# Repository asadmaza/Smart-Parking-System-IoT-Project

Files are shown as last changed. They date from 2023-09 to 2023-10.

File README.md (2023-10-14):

# Group3-CITS5506-2023
Repository for Group 3 Course CITS5506 2023 Second Semester

# Final Code to Use in Presentation and Vide
1. webApplication/indexAlternate.py
2. 8. RPI Local Script/integration_scriptV3.py

## To Do List
### raspberry Script
    - make a v4 of asad's local script that actually 
        1. publish to the aws iot core topic
        2. subscribe to the aws iot core topic
        3. init the bay states by publish a message to the topic and waiting for the appropriate response

### web application    
    - going to assume the booking entry time is always from right now until designated booking exit time
    - going to assume the reserved bay is only for people who make reservation beforehand
    - if a reservation is expired, then the bay will return to the state of can be reserved and customer needs to reserved it first before park their car in it

    -- Nice to Have --
    - Create input validation for the booking form
    - Change the web UI to accommodate for camera streaming on the situation of the parking bay
    - Send email to customer whenever a parking bay is reserved from the webapp
    - Apply best practice such as separate config

### Potential Improvement
#### Web application side
    - safeguard from racing condition
    - implement payment method
    - user account implementation

## How to run
1. create a new virtual environment
    python3 -m venv venv
2. activate environment
    > on macOS/Linux
        venv/bin/activate
    > on windows
        venv\Scripts\activate.bat
3. install requirement
    pip install -r requirements.txt
4. run the web app
    cd webApplication
    flask --app index run

## How to create local db for testing or maybe funsies
1. install sqlite3
2. cd to webApplicatoin/databaseStruct
3. run
    sqlite3 mockIoTDB.db < initdb.sql 
4. run to populate the mock data to the database
    cat insertToDetail.sql | sqlite3 mockIoTDB.db

## How to contribute
If you are interested to do one of the function that's in the web application section please do this first
1. make a new branch from this aji_branch or main branch if this is already merged
    git checkout -b "<insert branch name>" - format the branch name like yourName_what_you_are_trying_to_do
2. make your changes
3. test it
4. stage and commit your work
    git add . -> do this in the Group3...... folder
    git commit -m "<insert commit message>"
5. push to your branch
    git push origin <branch_name>
6. create a pull request

# Feel free to DM if you have anything to ask

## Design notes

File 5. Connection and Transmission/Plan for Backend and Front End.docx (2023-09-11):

Communication to a Database Proposed architecture for minimum functionality (Work in Progress):

1. AWS IoT Core
  1. Setup
    i. Prepare device

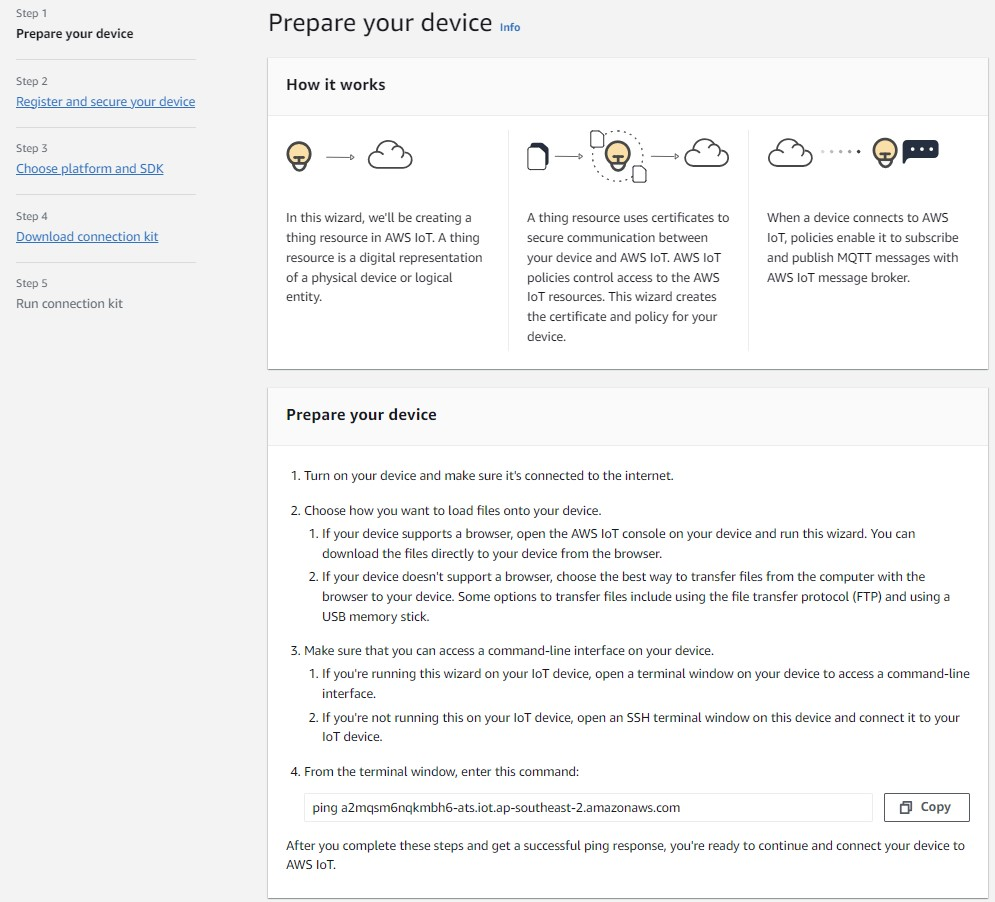
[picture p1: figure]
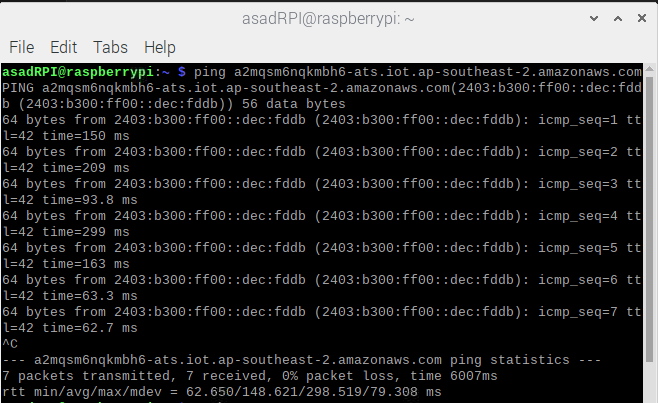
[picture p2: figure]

    ii. Register and secure device

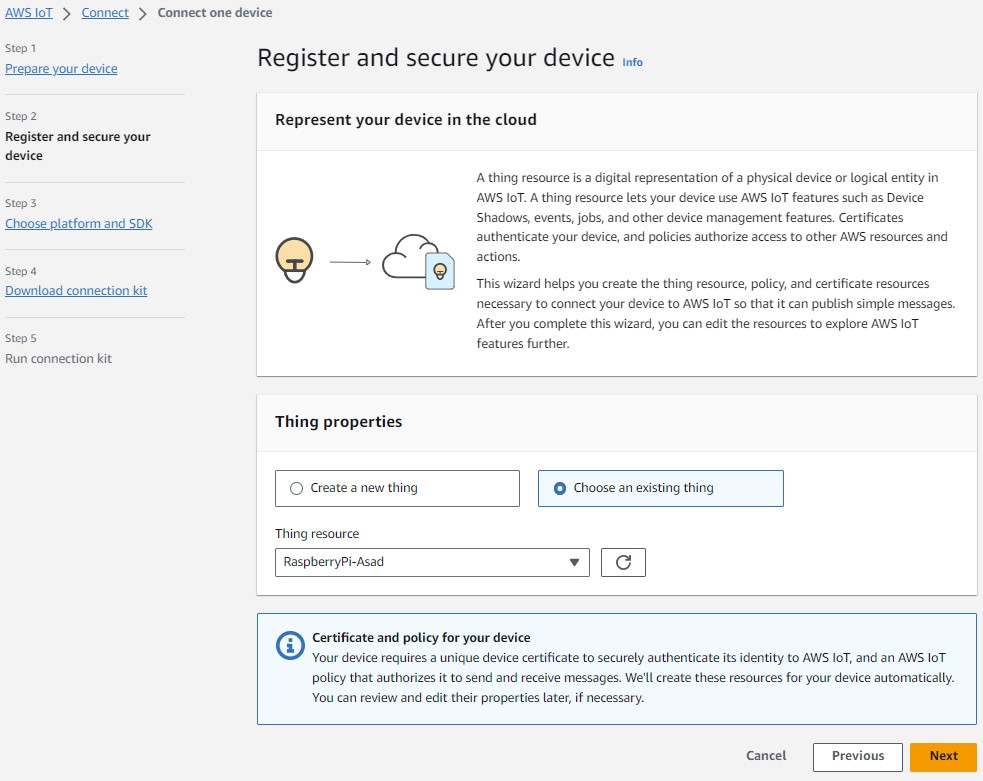
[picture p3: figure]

    iii. Choose platform and SDK

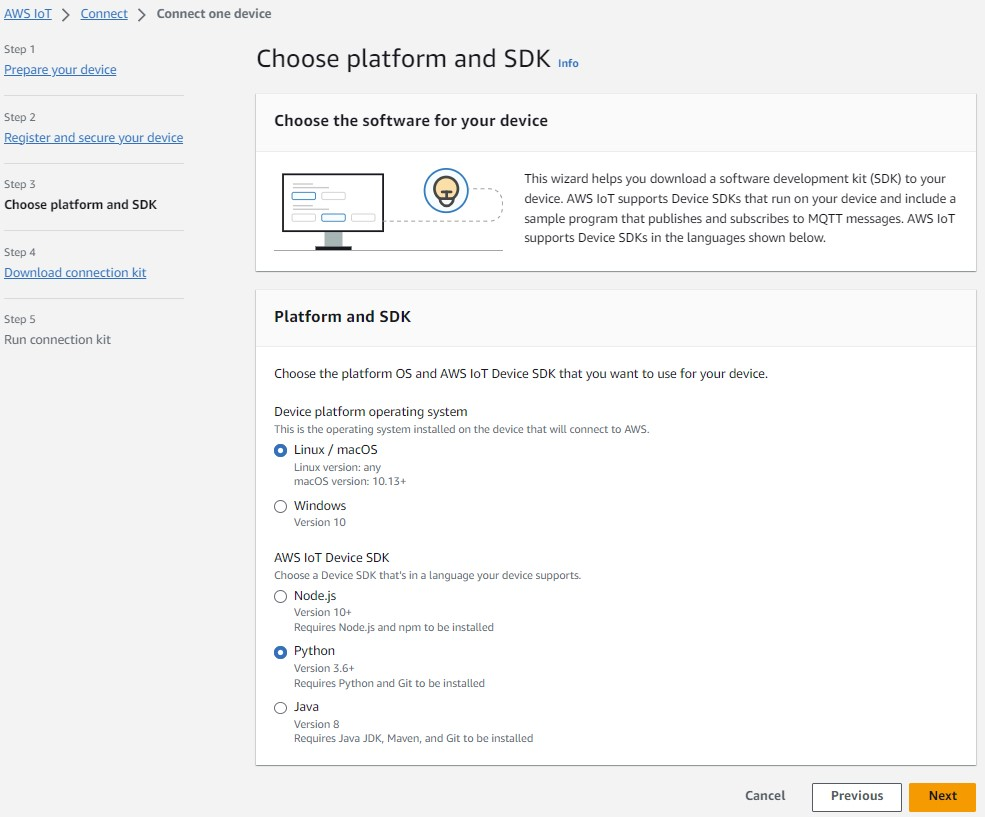
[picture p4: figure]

    iv. Download connection kit

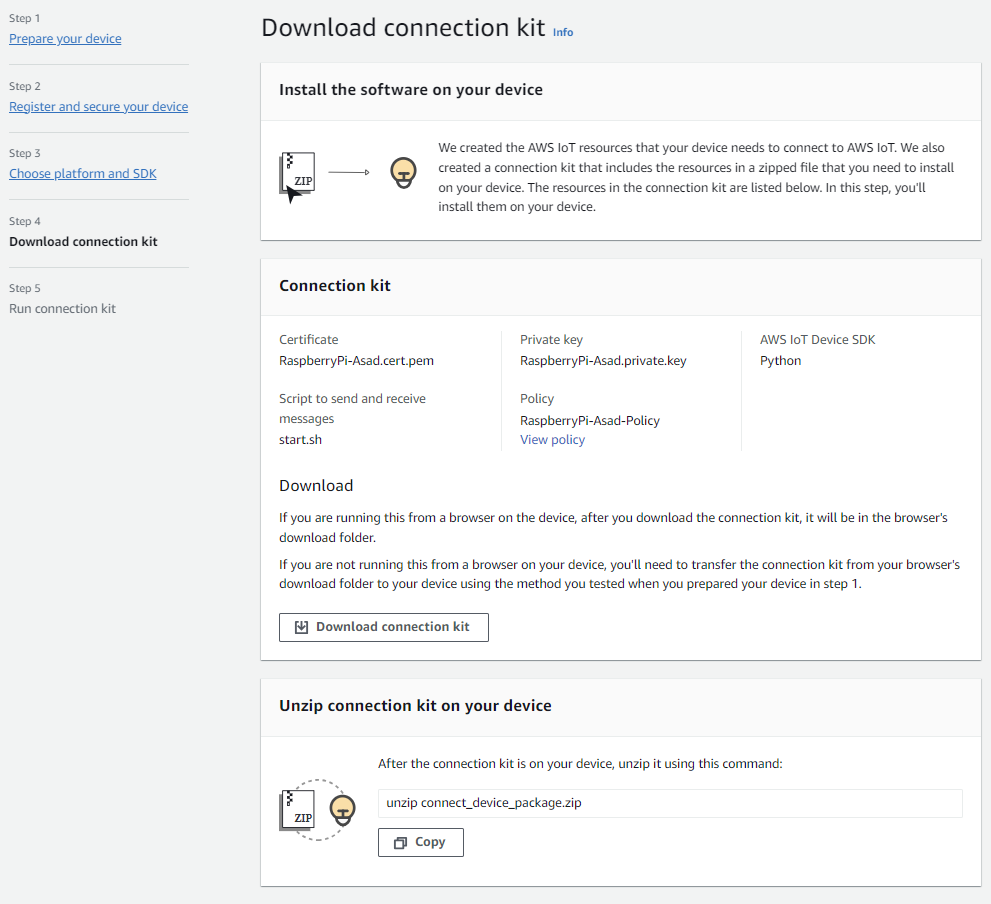
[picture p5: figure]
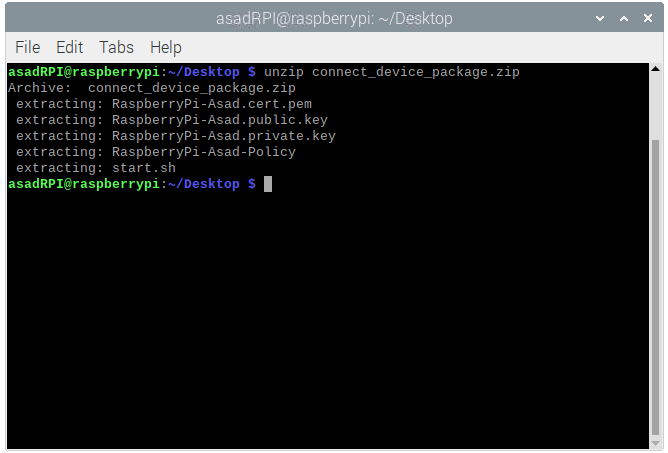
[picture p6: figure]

    v. Run connection kit on device

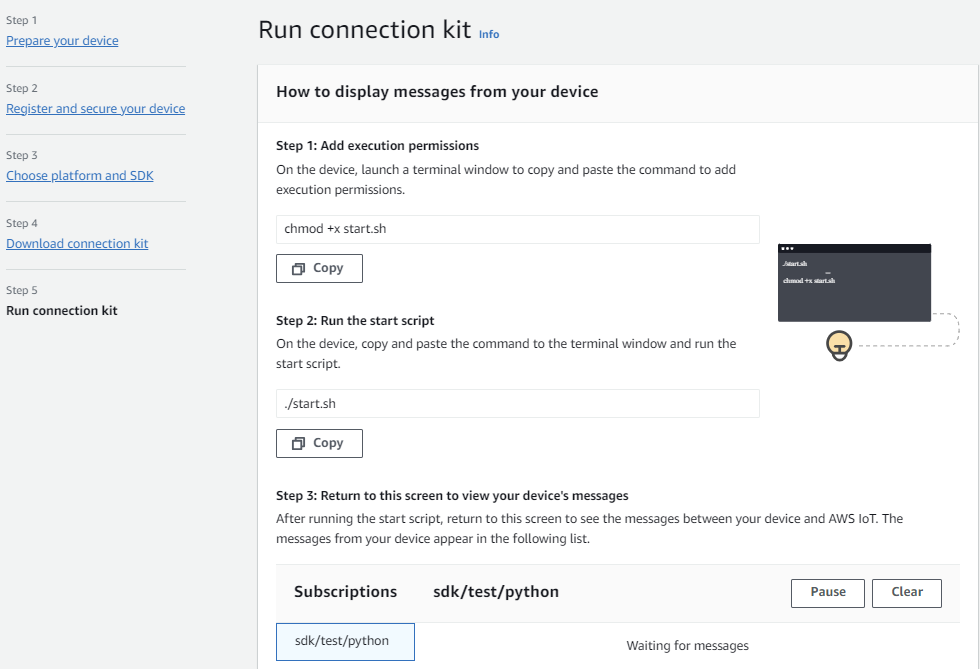
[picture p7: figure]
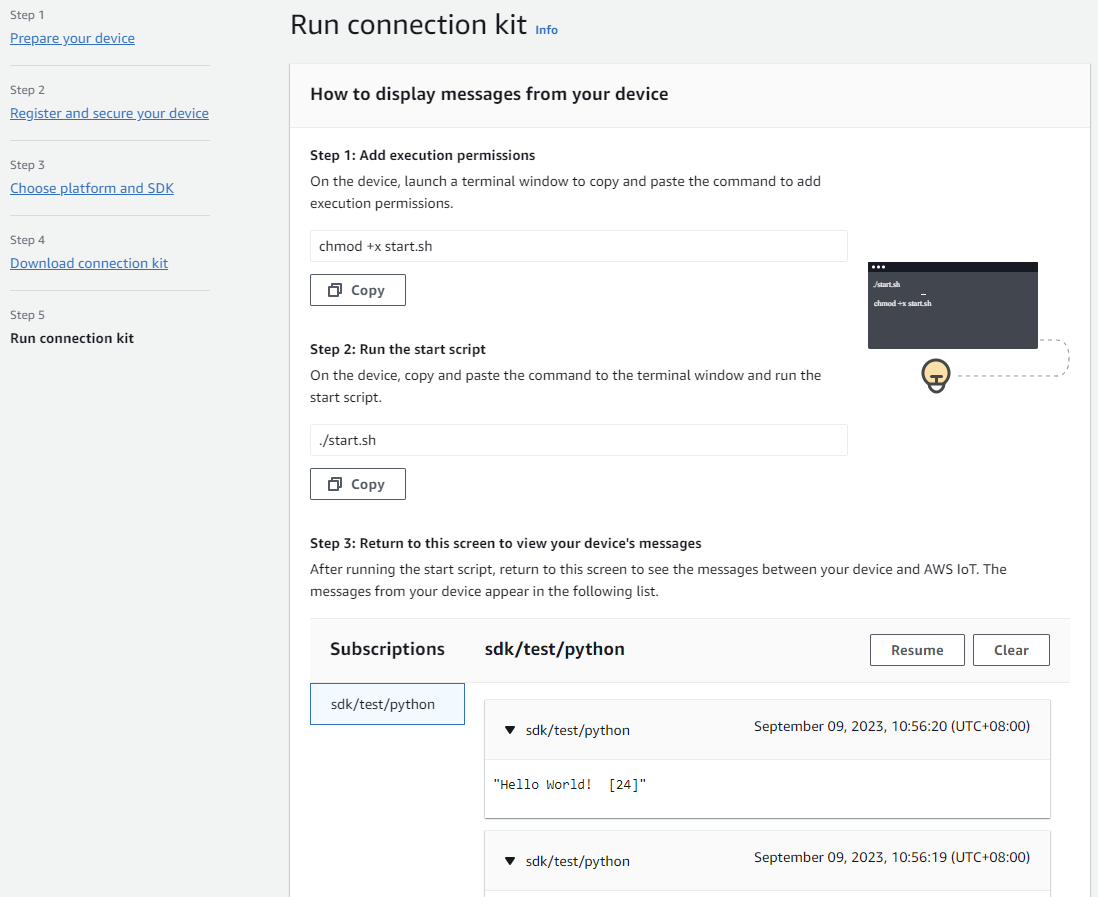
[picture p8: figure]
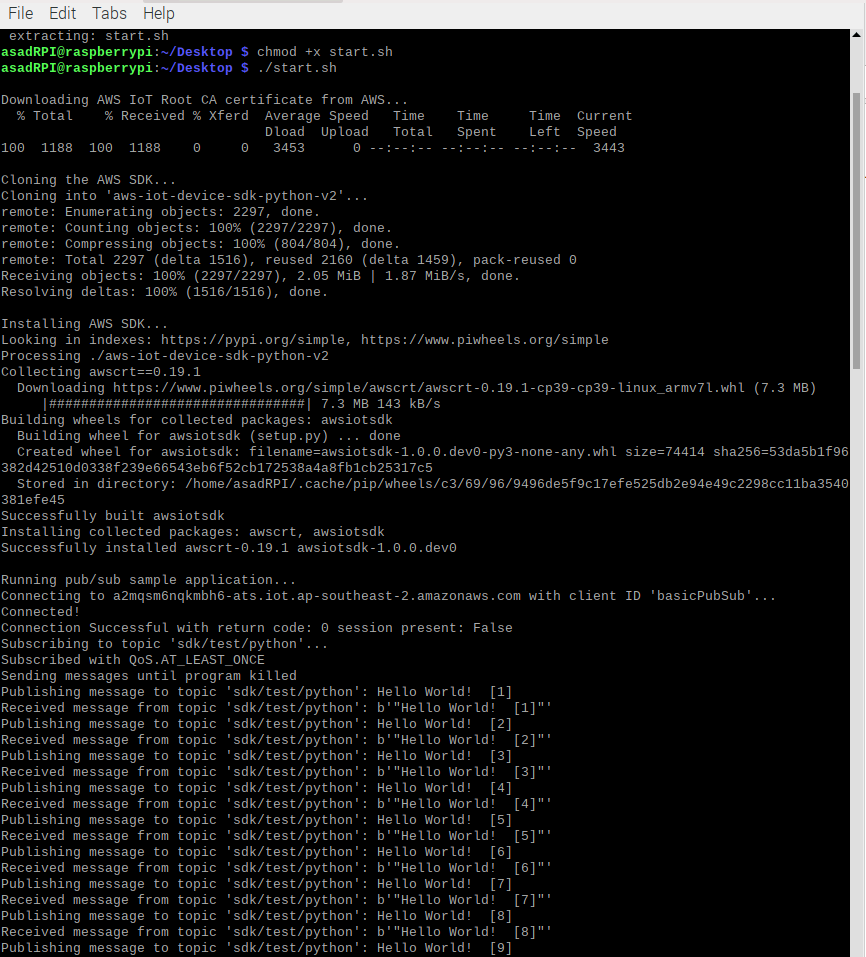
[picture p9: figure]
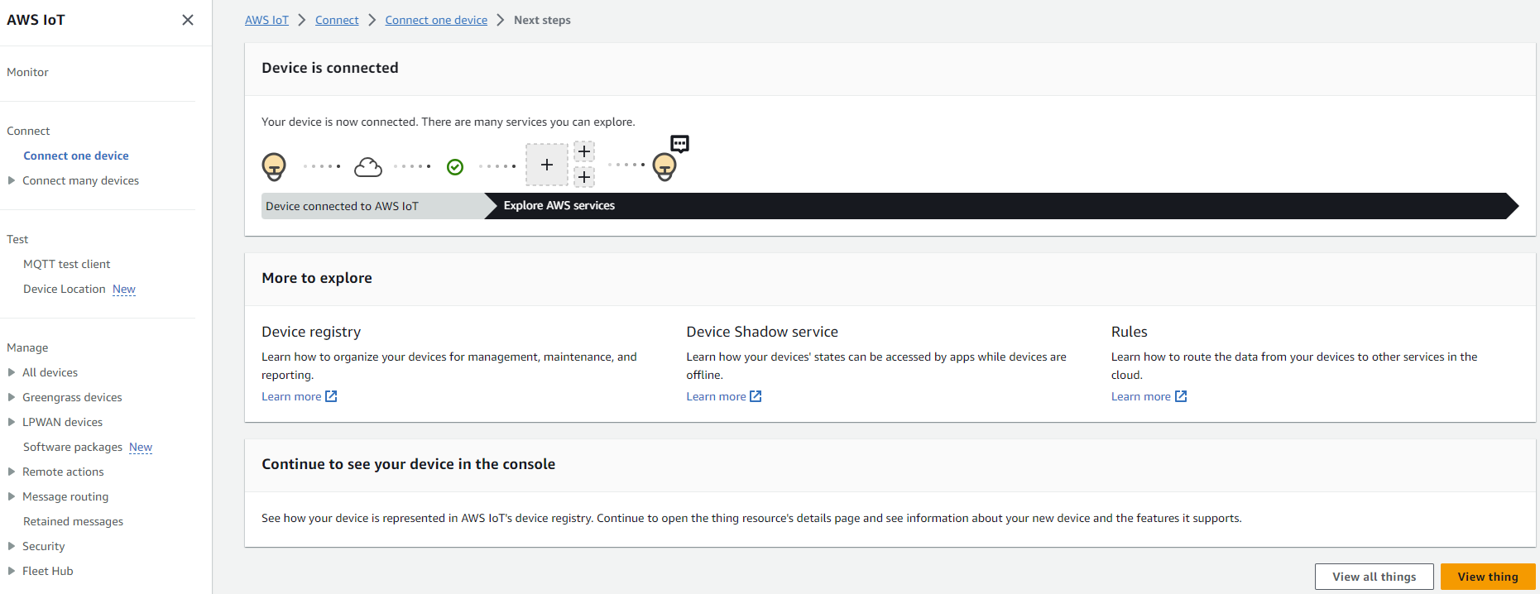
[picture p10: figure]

2. Python Script on Raspberry Pi
  a. Used Simulated Test.py
  b. Setup Security Policy under Thing to accept credentials and client connection
  c. Testing shown below:

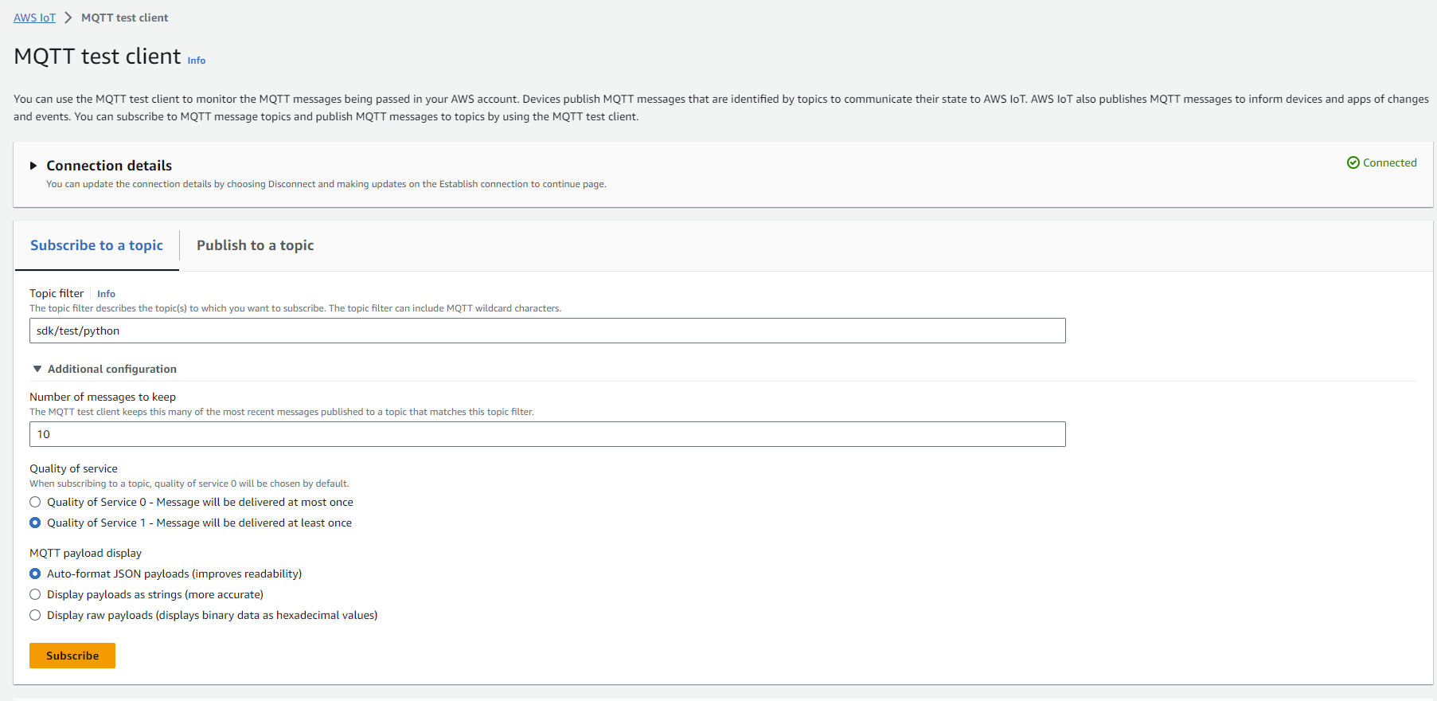
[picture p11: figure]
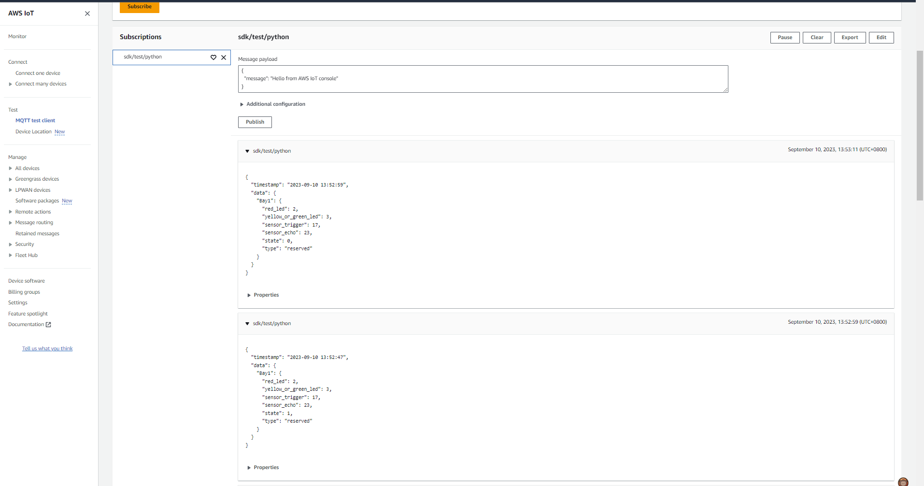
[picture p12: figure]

3. AWS Lambda for function
4. AWS DynamoDB for Database
5. AWS Amplify Studio for building the WebApp
  a. Figma for design

Communication to Database Proposed architecture for maximum functionality (livestreaming video) Work in Progress:

1. Python Script on Raspberry Pi
2. AWS IoT Core - AWS Kinesis Video Streams for Video
3. AWS IoT Core
4. …. Not sure need to look into this

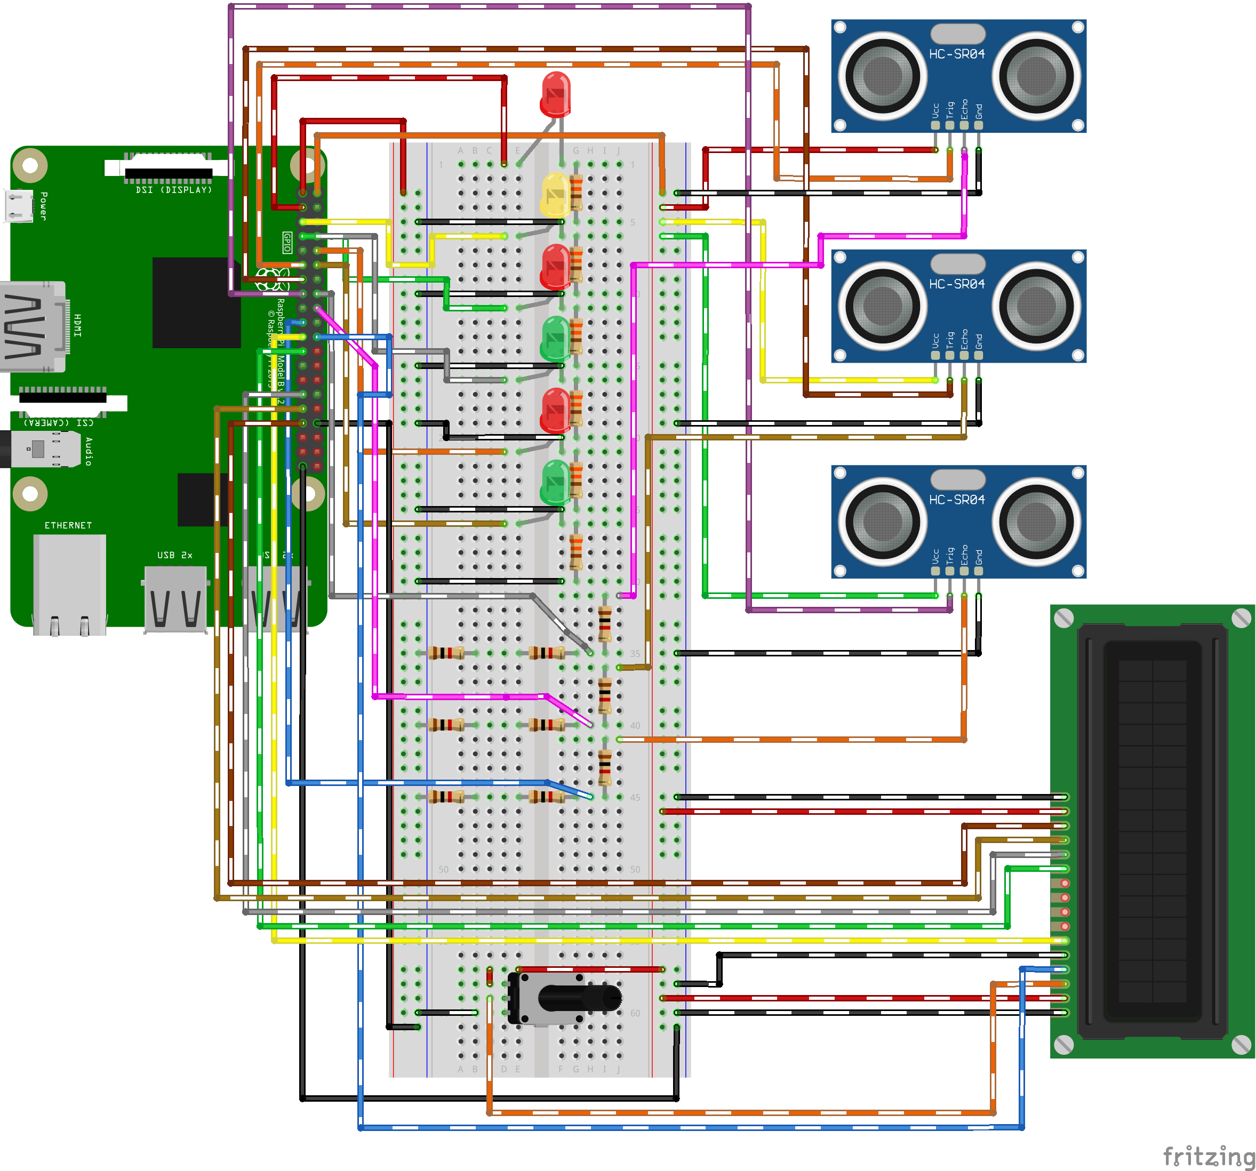
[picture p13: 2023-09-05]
0. IOT Schematics/Complete Minimum/Smart Parking System Complete.png

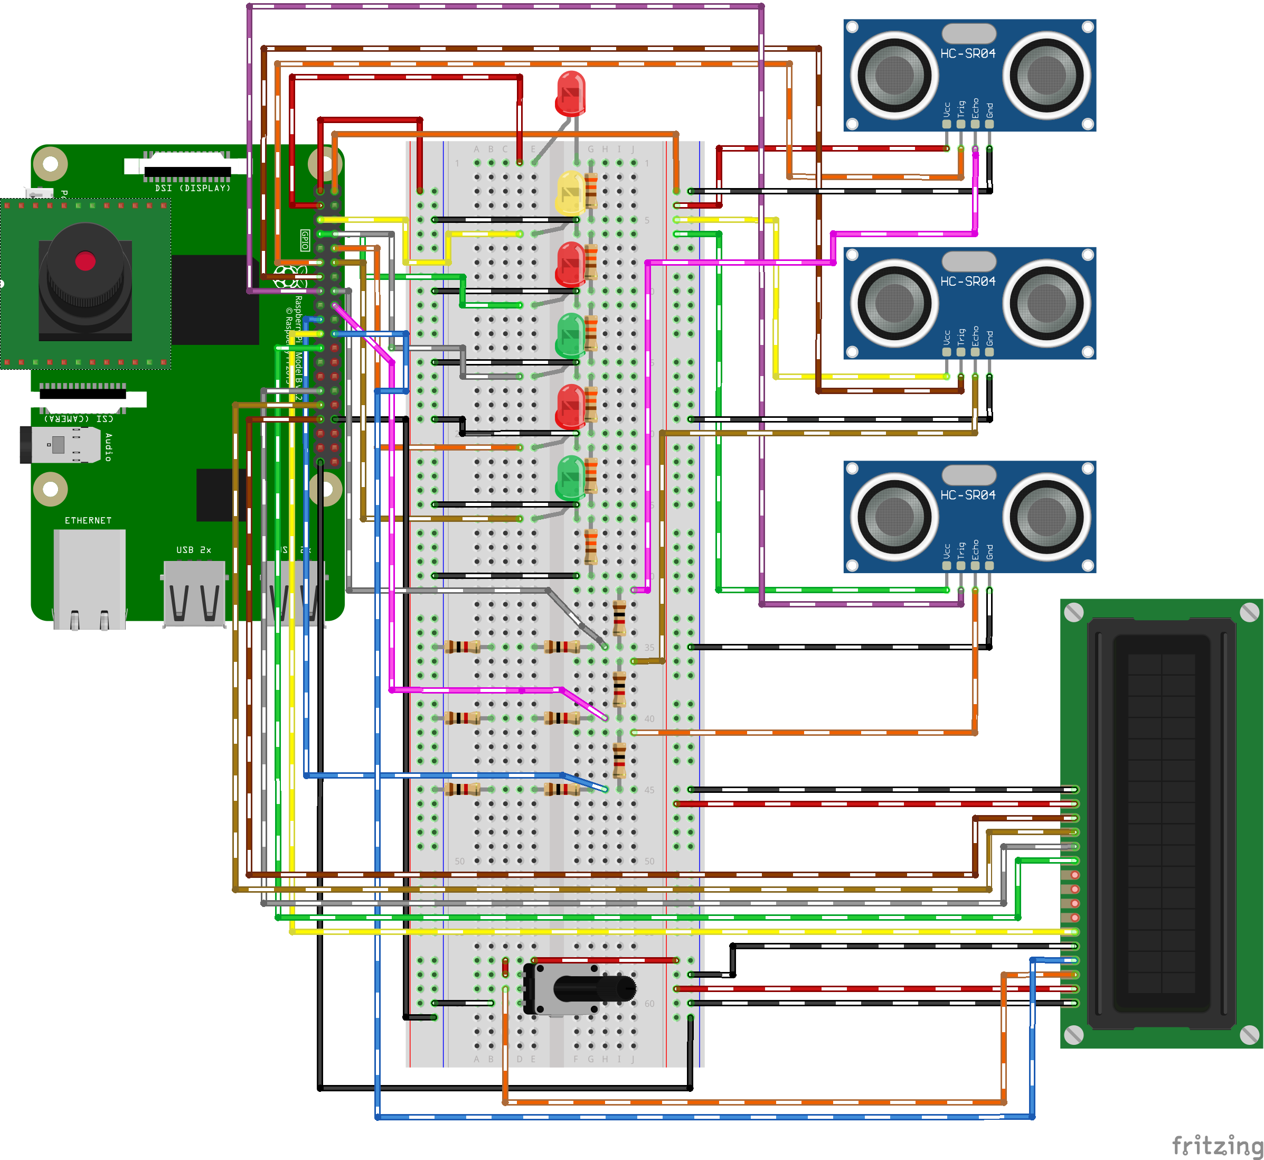
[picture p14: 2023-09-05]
0. IOT Schematics/Complete w Camera/Smart Parking System Complete w Camera.png

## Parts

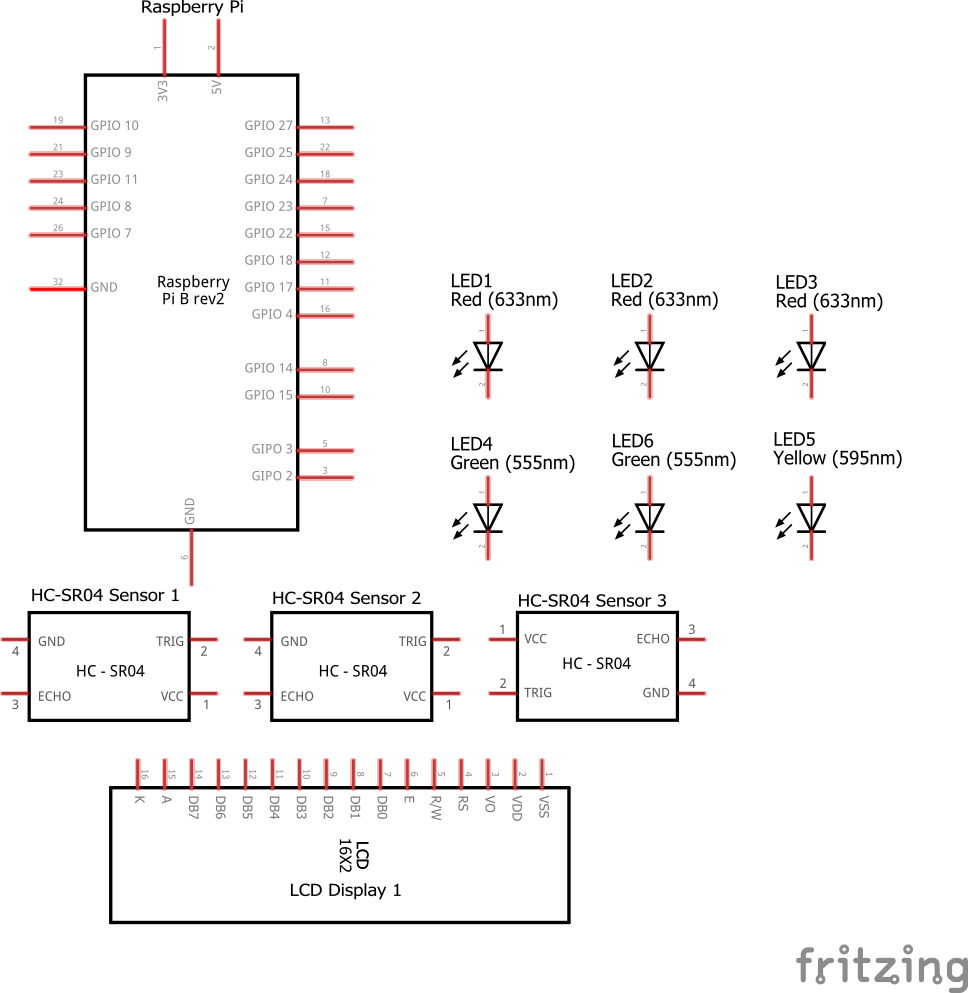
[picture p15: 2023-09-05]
0. IOT Schematics/Parts/Leds Sensor Display/Pi LEDs Sensor Display.png

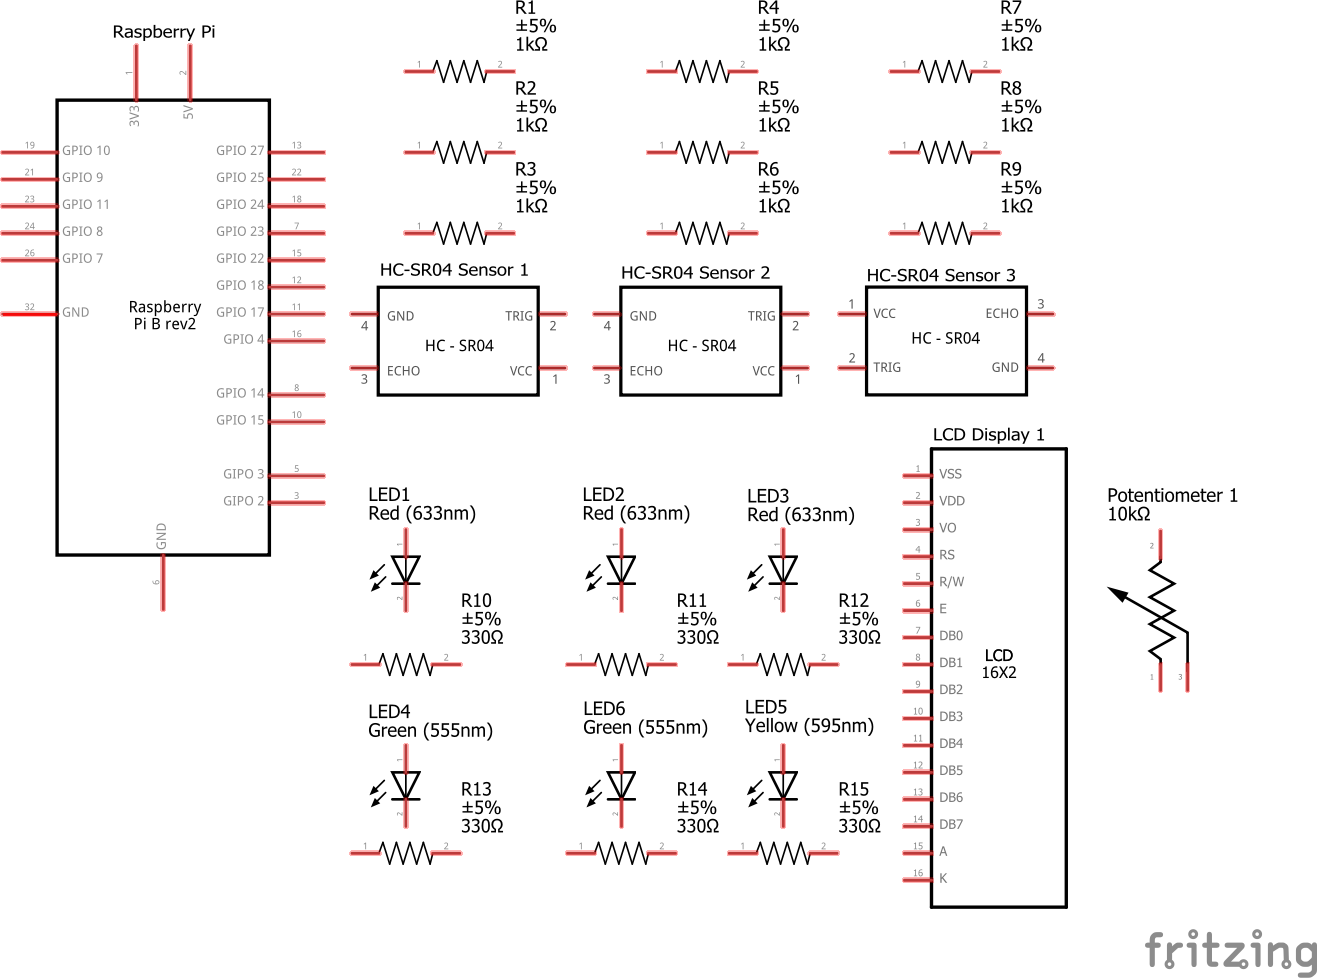
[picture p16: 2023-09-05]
0. IOT Schematics/Parts/Final excl Camera/Pi LEDs Sensor Display Resistors and Pot.png

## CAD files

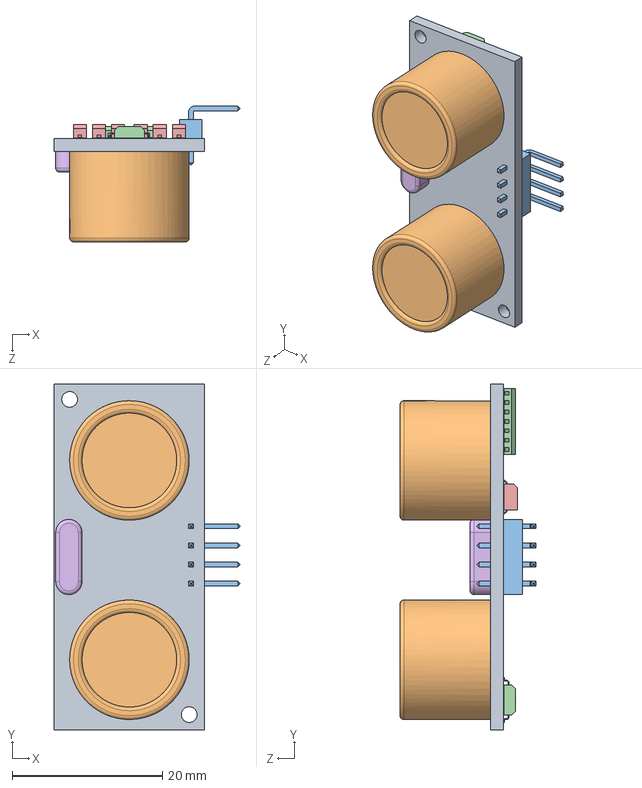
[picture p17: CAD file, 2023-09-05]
7. 3D models (Print)/ultrasonic-sensor-housing-hc-sr04-1.snapshot.1/HC-SR04 Ping Sensor.SLDASM
24.7 x 46.0 x 18.1 mm
PCB
Transducer x 2
3 Pin Header 90 Degree
14 Pin SMT x 3
Cap1 SMT x 6
HC-SR04 Crystal.SLDASM

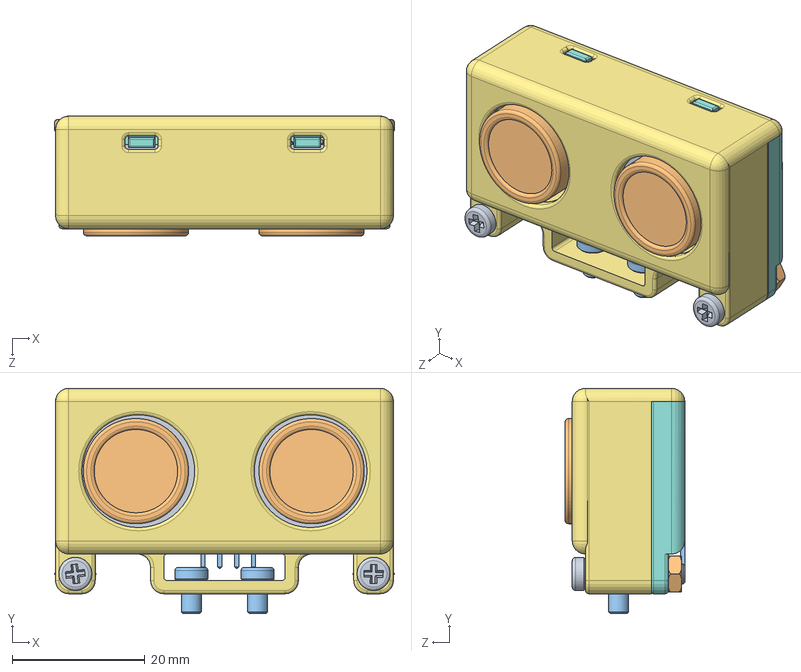
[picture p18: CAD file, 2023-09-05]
7. 3D models (Print)/ultrasonic-sensor-housing-hc-sr04-1.snapshot.1/porta-HC04.SLDASM
51.3 x 34.0 x 18.1 mm
PCB
Transducer x 2
3 Pin Header 90 Degree
14 Pin SMT x 3
Cap1 SMT x 6
HC-SR04 Crystal.SLDASM
porta-HC04-1
porta-HC04-2
M3-Tornillo-15mm x 2
M3-Tuerca x 2
M3-Tornillo-5mm x 2

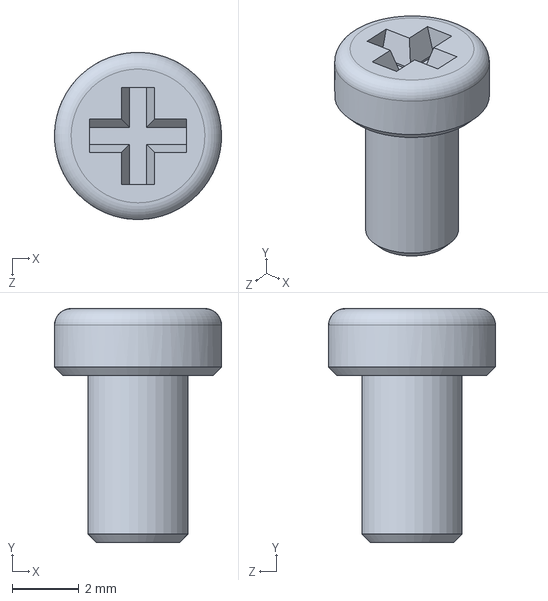
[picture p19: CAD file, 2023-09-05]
7. 3D models (Print)/ultrasonic-sensor-housing-hc-sr04-1.snapshot.1/M3-Tornillo-5mm.SLDPRT
5.00 x 7.00 x 5.00 mm

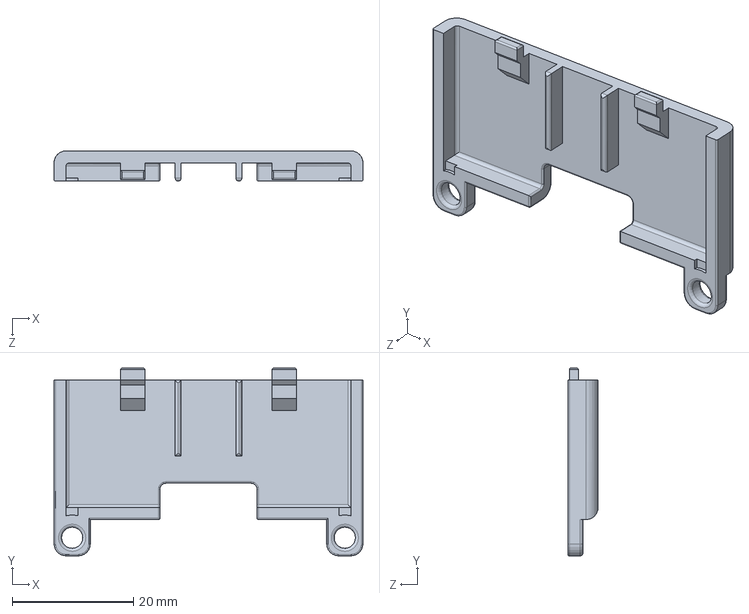
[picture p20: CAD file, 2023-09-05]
7. 3D models (Print)/ultrasonic-sensor-housing-hc-sr04-1.snapshot.1/porta-HC04-2.SLDPRT
51.0 x 31.0 x 5.00 mm

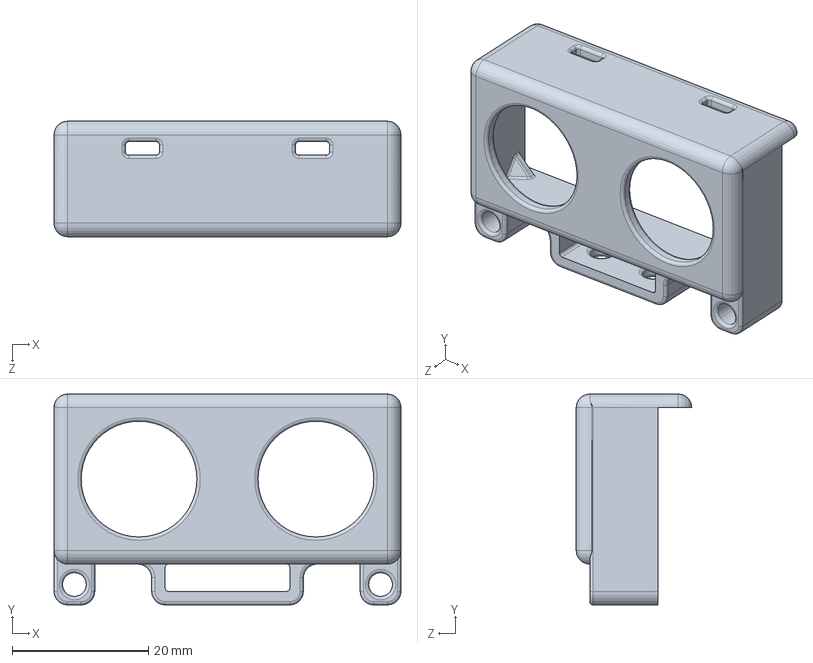
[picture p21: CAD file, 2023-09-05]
7. 3D models (Print)/ultrasonic-sensor-housing-hc-sr04-1.snapshot.1/porta-HC04-1.SLDPRT
51.0 x 31.0 x 17.0 mm

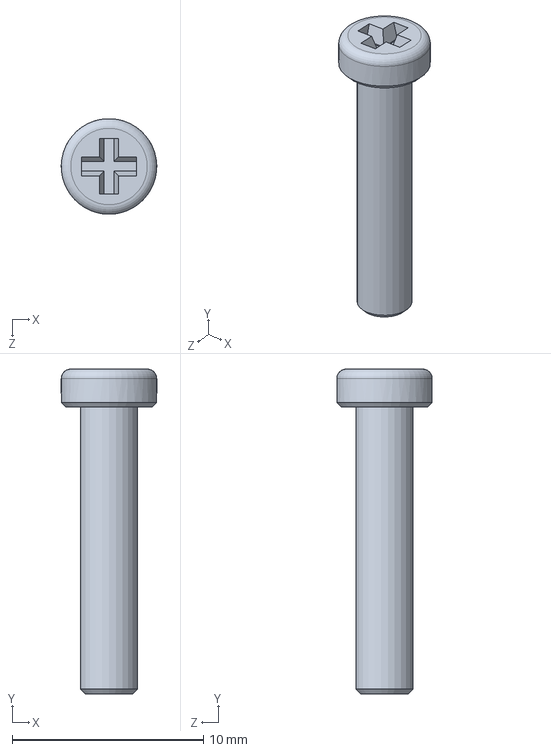
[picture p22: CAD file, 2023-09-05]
7. 3D models (Print)/ultrasonic-sensor-housing-hc-sr04-1.snapshot.1/M3-Tornillo-15mm.SLDPRT
5.00 x 17.0 x 4.99 mm

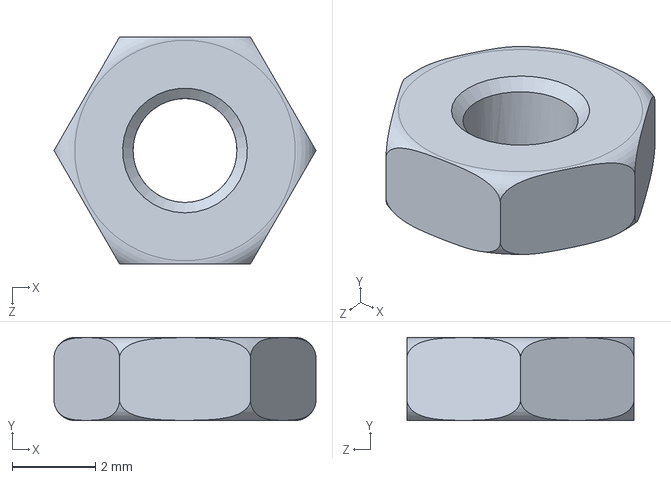
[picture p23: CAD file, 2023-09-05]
7. 3D models (Print)/ultrasonic-sensor-housing-hc-sr04-1.snapshot.1/M3-Tuerca.SLDPRT
6.30 x 2.00 x 5.46 mm

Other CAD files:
7. 3D models (Print)/ultrasonic-sensor-housing-hc-sr04-1.snapshot.1/porta-HC04-1.STL
7. 3D models (Print)/ultrasonic-sensor-housing-hc-sr04-1.snapshot.1/porta-HC04-2.STL

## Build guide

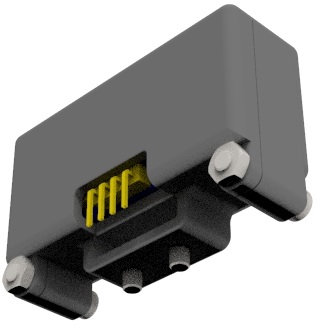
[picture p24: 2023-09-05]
7. 3D models (Print)/ultrasonic-sensor-housing-hc-sr04-1.snapshot.1/untitled.20.jpg

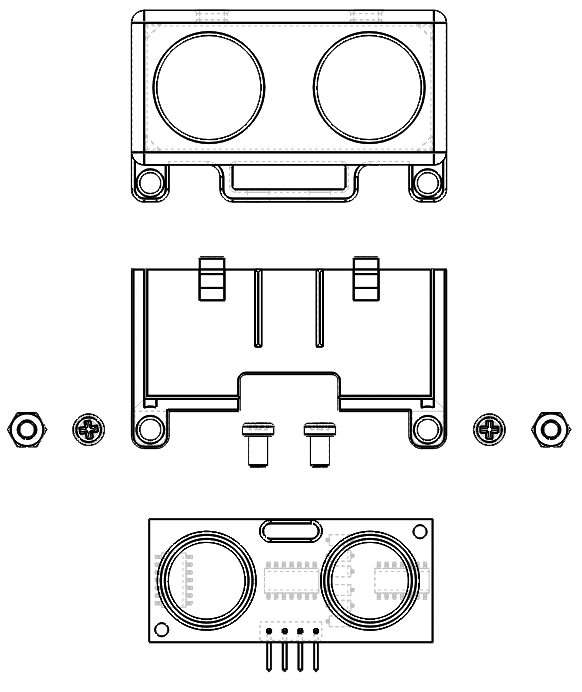
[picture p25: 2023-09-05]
7. 3D models (Print)/ultrasonic-sensor-housing-hc-sr04-1.snapshot.1/Sin título.png

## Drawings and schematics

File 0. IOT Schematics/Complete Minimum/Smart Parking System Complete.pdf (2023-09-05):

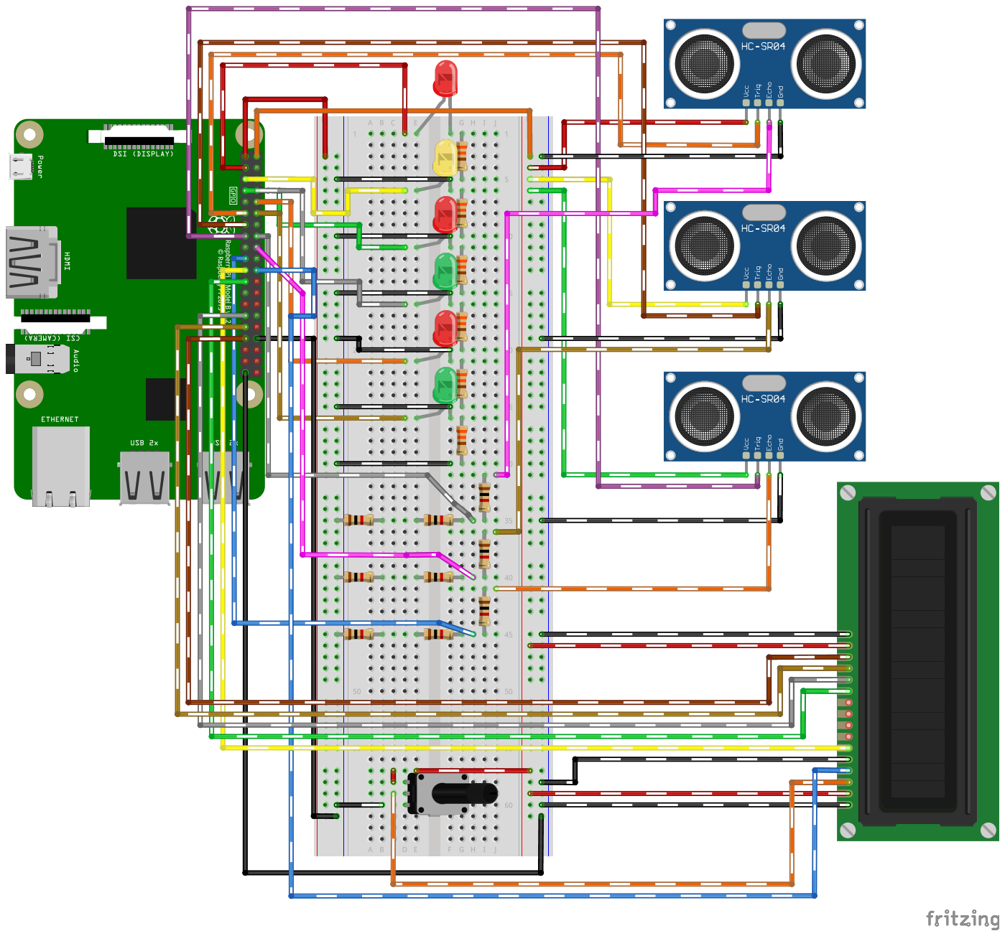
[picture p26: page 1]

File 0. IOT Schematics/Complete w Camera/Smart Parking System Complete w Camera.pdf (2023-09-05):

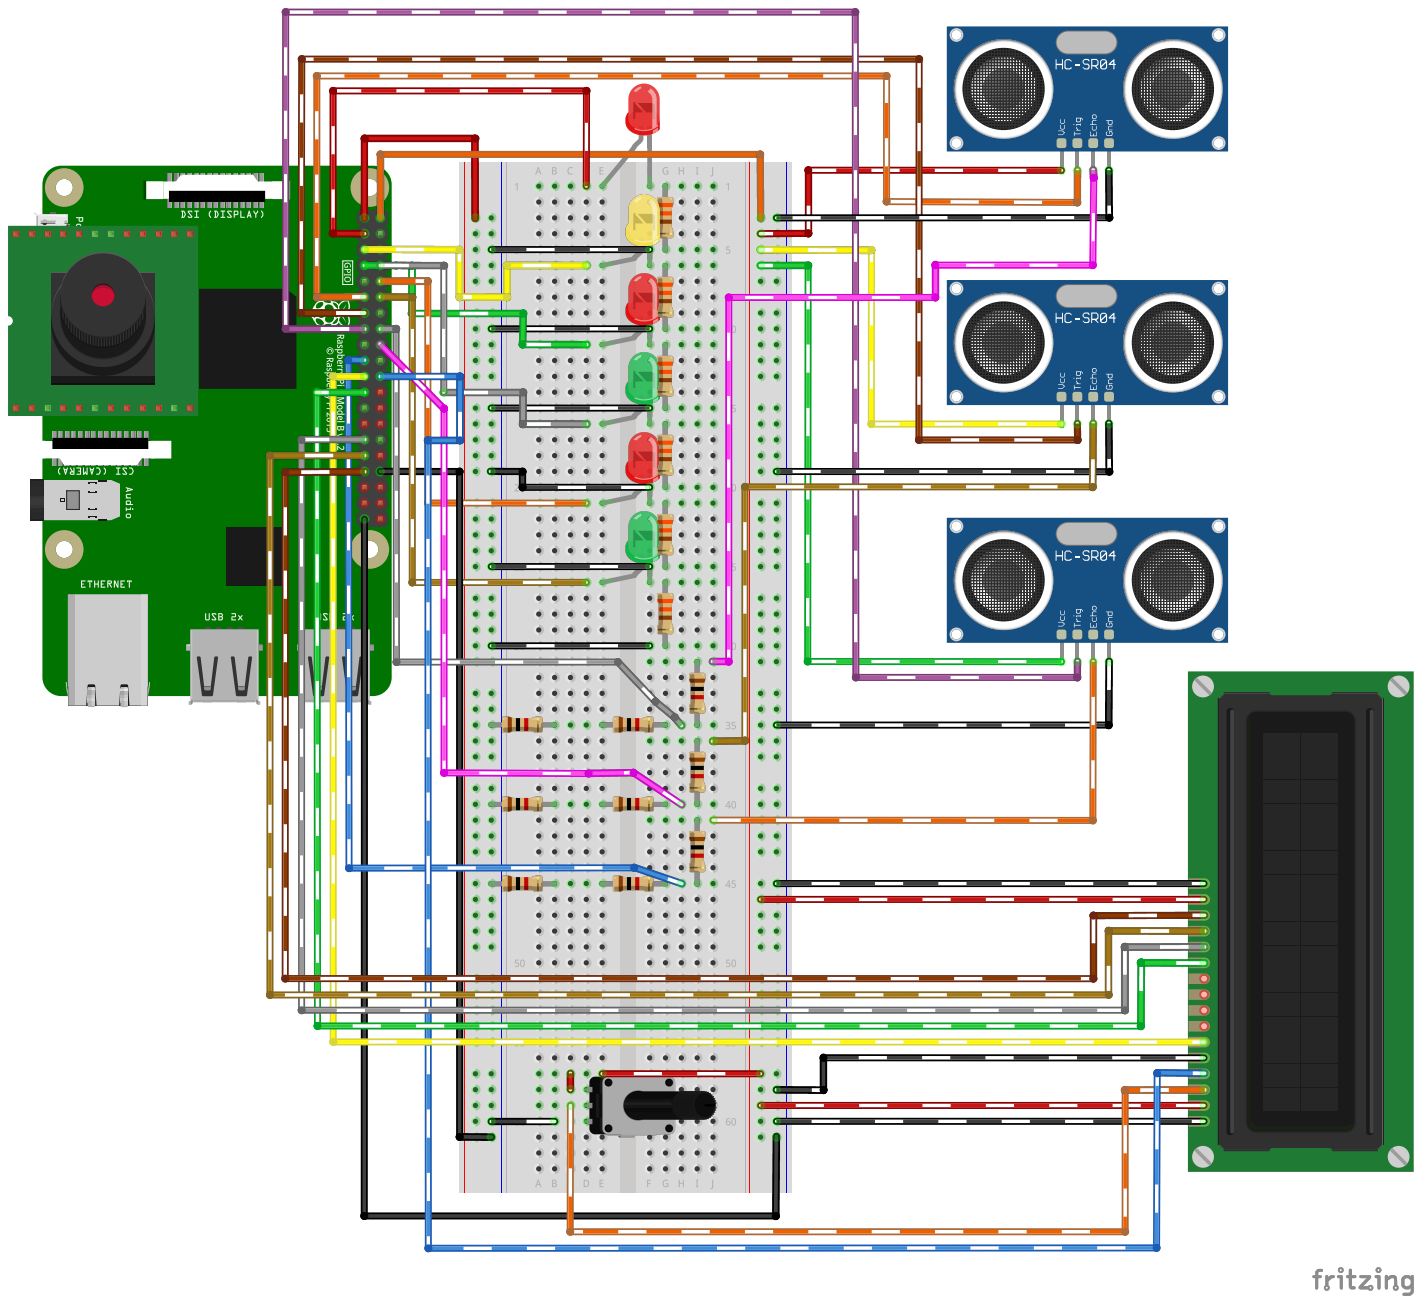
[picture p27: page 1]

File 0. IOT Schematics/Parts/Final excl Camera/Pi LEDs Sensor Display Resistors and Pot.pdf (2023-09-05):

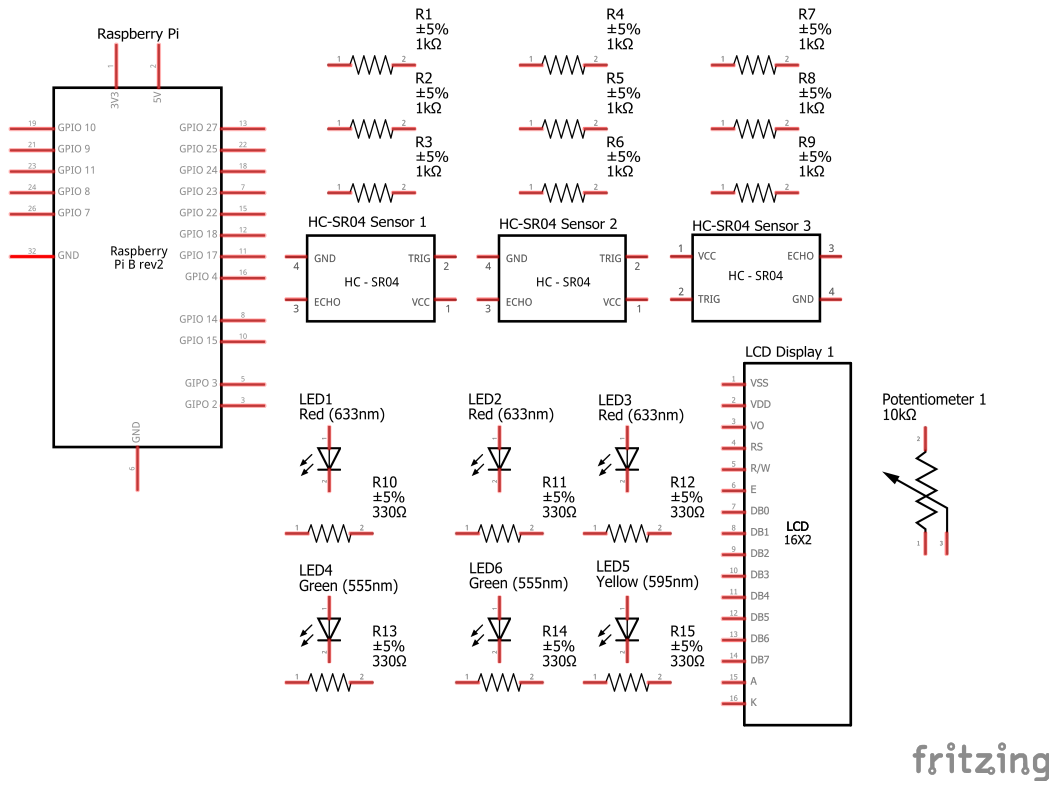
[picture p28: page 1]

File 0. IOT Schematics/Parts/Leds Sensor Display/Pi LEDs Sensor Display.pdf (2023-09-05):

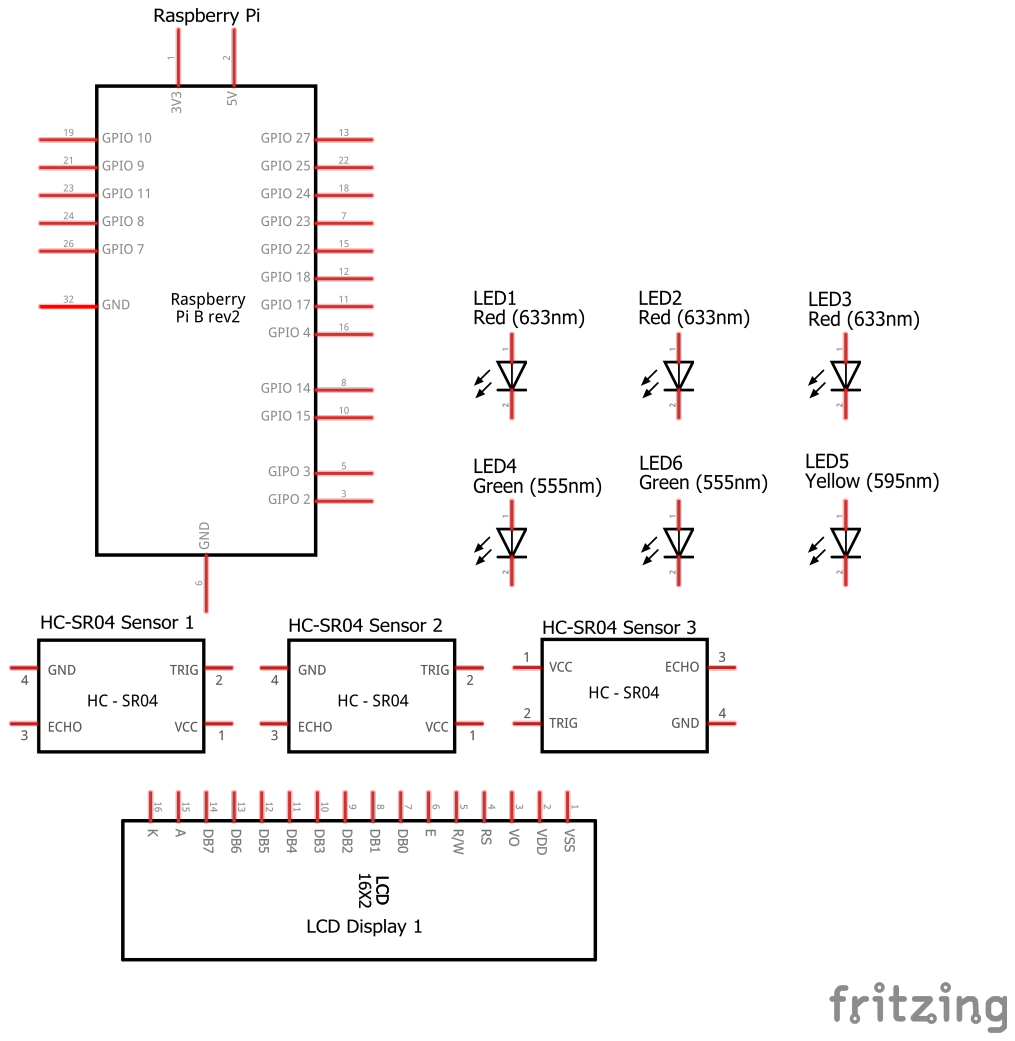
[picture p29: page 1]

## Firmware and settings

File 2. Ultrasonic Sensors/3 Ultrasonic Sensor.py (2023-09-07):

"""
====================================================================
ONLY RUN AFTER YOU HAVE DOUBLE CHECKED CONNECTIONS AS COMPONENTS
CAN BE DAMAGED IF INCORRECTLY WIRED.
====================================================================
Test file for 3 HC-SR04 Ultrasonic sensors.
Use this file to test 3 Ultrasonic sensors for the project.

Components required:
x3 HC-SR04 Ultrasonic Sensor
x1 Raspberry Pi Kit (RPI, cables, power source, breadboard etc.)
x9 1K ohm resistor

Code description:
This code controls 3 HC-SR04 ultrasonic sensors with a Raspberry Pi
to measure and print the distance to objects in centimeters for each
sensor, updating every second.
--------------------------------------------------------------------
Setup:

Ensure all 3 Ultrasonic sensors are connected as described:

Ultrasonic sensor 1:
• VCC connects to Pin 2 (5V)
• Trig connects to Pin 11 (GPIO 17)
• Echo connects to R1 (1k OHM)
• R2 and R3 (1k OHM + 1 k OHM) connects from R1 to Ground
• Wire from R1 and R2+R3 connects to Pin 16 (GPIO 23)
• GND connects to Pin 34 (Ground)

Ultrasonic sensor 2:
• VCC connects to Pin 2 (5V)
• Trig connects to Pin 11 (GPIO 27)
• Echo connects to R1 (1k OHM)
• R2 and R3 (1k OHM + 1 k OHM) connects from R1 to Ground
• Wire from R1 and R2+R3 connects to Pin 16 (GPIO 24)
• GND connects to Pin 34 (Ground)

Ultrasonic sensor 3:
• VCC connects to Pin 2 (5V)
• Trig connects to Pin 11 (GPIO 22)
• Echo connects to R1 (1k OHM)
• R2 and R3 (1k OHM + 1 k OHM) connects from R1 to Ground
• Wire from R1 and R2+R3 connects to Pin 16 (GPIO 10)
• GND connects to Pin 34 (Ground)
--------------------------------------------------------------------

Date: 03/09/2023
Author: Asad Maza - Group 3

====================================================================
ONLY RUN AFTER YOU HAVE DOUBLE CHECKED CONNECTIONS AS COMPONENTS
CAN BE DAMAGED IF INCORRECTLY WIRED.
====================================================================
"""

# Imports
import RPi.GPIO as GPIO
import time
from time import sleep as sleep
from gpio_reset import all_pins_to_off

# Set all pins to off before main code
all_pins_to_off()
# GPIO config
GPIO.setmode(GPIO.BCM)
GPIO.setwarnings(False)

# Define GPIO pins
sensor_data = [
    {'TRIG': 17, 'ECHO': 23},  # Sensor 1
    {'TRIG': 27, 'ECHO': 24},  # Sensor 2
    {'TRIG': 22, 'ECHO': 10}   # Sensor 3
]

# Setup GPIO
for sensor in sensor_data:
    GPIO.setup(sensor['TRIG'], GPIO.OUT)
    GPIO.setup(sensor['ECHO'], GPIO.IN)
    
# Define distance measuring function
def distance(TRIG, ECHO):
    # Trigger sensor
    GPIO.output(TRIG, True)
    time.sleep(0.00001)
    GPIO.output(TRIG, False)

    start_time = time.time()
    stop_time = time.time()

    # Measure start and stop time
    while GPIO.input(ECHO) == 0:
        start_time = time.time()
    while GPIO.input(ECHO) == 1:
        stop_time = time.time()

    # Calculate distance
    time_elapsed = stop_time - start_time
    distance = (time_elapsed * 34300) / 2

    return distance

# main loop
if __name__ == '__main__':
    try:
        while True:
            for i, sensor in enumerate(sensor_data):
                dist = distance(sensor['TRIG'], sensor['ECHO'])
                print(f"Measured Distance from Sensor {i+1} = {dist:.1f} cm")
            print('-'*30)
            time.sleep(1)

    # Break out
    except KeyboardInterrupt:
        print("Measurement stopped")
        all_pins_to_off()

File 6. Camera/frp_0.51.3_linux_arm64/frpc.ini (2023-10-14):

[common]
server_addr = 3.106.140.164
server_port = 7000

[ssh]
type = tcp
local_ip = 127.0.0.1
local_port = 22
remote_port = 6000

[video]
local_ip = 127.0.0.1
local_port = 8081
remote_port = 8081
use_compression = true
use_encryption = true

[vnc]
type = tcp
local_ip = 127.0.0.1
local_port = 5900
remote_port = 6900

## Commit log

2023-09-04 initiate flask web app and raspberry pi mock script
2023-09-05 My initial commit. All test code completed except 4 and 5. 8 and 9 to be created later. 7 still need to figure out how to modify this enclosure.
    [HC-SR04 Ping Sensor.SLDASM, M3-Tornillo-15mm.SLDPRT, M3-Tornillo-5mm.SLDPRT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]
2023-09-06 Added test code for Pi Camera Module 3, this one might need further testing..
2023-09-07 Added 10. Datasheet folder - useful for power consumption and tech specs
2023-09-07 gpio_reset module created, fixed import errors in LEDs and Ultrasonic sensors
    [3 Ultrasonic Sensor.py, 6 LEDs.py, Single Ultrasonic Sensor.py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]
2023-09-07 finalised LED and Ultrasonic sensor files should be ready to use in testing
2023-09-07 Created local raspberry pi script see 8. RPI Local Script. All based on my schematics 0. IOT schematics. Need to modify further for any DB setup and communication to backend.
2023-09-09 Updated 6. Camera/PiCamera3Test.py, updated setup and fixed errors in script
    [PiCamera3Test.py]
2023-09-10 Updated local scriptv3, more responsive polling ultrasonic sensors, changed files
2023-09-19 maybe done for the change from raspberry pi
2023-09-24 add page to camera feed link
2023-10-04 should be finish with raspberry pi script, need fine tuning
2023-10-04 fix final raspi script
    [test_scriptV1.py]
2023-10-10 Added testing folder and ultrasonic sensor testing python file
2023-10-10 Updated ultrasonic.py comments in testing folder
2023-10-10 Updated code for the magcar (magnet sensor).
2023-10-10 Created multimodal test files for AND OR testing for multimodal sensors
2023-10-11 fix multimodal OR script
    [Multimodal test AND.py, Multimodal test OR.py]
2023-10-11 additional sensor files, not sure
2023-10-11 insert frpc config
2023-10-11 adjust pin number
2023-10-11 calibrated for toy multimodal and or files
2023-10-13 add integration script v3, need adjust on LED numbering and sequencing
2023-10-14 fix integration script final
    [integration_scriptV3.py]
2023-10-20 Pushing files from the main branch on Raspberry Pi
